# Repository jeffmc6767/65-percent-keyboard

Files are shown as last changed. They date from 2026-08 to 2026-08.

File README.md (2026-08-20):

67% Keyboard
-
A 60-70% keyboard with a customizable oled and 2 rotary encoders. 
Screenshot 2026-08-13 at 2 15 45 PM

Quick start
-

How can you build it yourself. 

1. Buy all the parts in the BOM (Also make sure to buy Cherry MX switches that are 3 or 5 pin) and order a PCB
2. solder everything according to the layout on the PCB
3. Install firmware by plugging in the raspberry pi pico 2wh and flashing it.
4. Customize keys in the software
5. Done!

Features:
-

1. 73 key keyboard, with 2 customizable keys
2. 2 rotary encoders for volume and brightness control(default)
3. Rotary encoders include push button
4. 1 0.91" customizable OLED screen

How it works:
-

The 73 switches and 2 rotary encoders are wired in a matrix, each with a diode to detect which key is pressed. Each switch is soldered directly to the PCB. 

The keyboard will be wireless via bluetooth, 2.4gz, and also supports USBC connection, since the raspberry pi pico2wh has wifi and bluetooth connectivity. 

Here's some images:
-

Screenshot 2026-08-13 at 2 16 21 PM
Screenshot 2026-08-13 at 2 16 12 PM
Screenshot 2026-08-13 at 1 37 29 PM

I will be using PLA matte white to print the case out (because it has no LED's) or petg white depending on what filament I have. 

ROUGH BOM: look at the BOM.csv. 

- 73x switches: $29.99(I own these already)
- 75x 1N4148 Diodes: $5
- 2x PEC11R-4220f-S0024-ND: $8.60
- 1x Raspberry Pi Pico 2WH: $21
- 1x 0.91" OLED: $9
- 1x Tin Lead Sn60-Pb40 (0.6mm, 50g): $12
- 1x PCB: $76
- 6.25U and 2.00U stabilizer: $15

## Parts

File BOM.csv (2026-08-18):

Item | Description | Part Number / Spec | Qty | Unit Price (CAD $) | Subtotal (CAD $) | 13% Tax (CAD $) | Total (CAD $) | Total (USD $) | Link
2 | Switching Diodes | 1N4148 | 75 | 0.07 | 5.00 | 0.65 | 5.65 | 4.07 | https://www.digikey.ca/en/products/detail/onsemi/1N4148/458603
3 | Rotary Encoder | PEC11R-4220F-S0024 | 2 | 4.30 | 8.60 | 1.12 | 9.72 | 7.00 | https://www.digikey.ca/en/products/detail/bourns-inc/PEC11R-4220F-S0024/4499660
4 | Microcontroller Board | Raspberry Pi Pico 2WH | 1 | 11.91 | 11.91 | 1.55 | 13.46 | 9.69 | https://www.digikey.ca/en/products/detail/raspberry-pi/SC1634/26241087
5 | OLED Display Module | 0.91" OLED (I2C) | 1 | 9.00 | 9.00 | 1.17 | 10.17 | 7.32 | https://www.amazon.ca/gp/product/B0CYXW1WPF/ref=ox_sc_saved_image_2?smid=A3NZ63JNHV007B&psc=1
6 | DigiKey Shipping Fee | Flat Shipping Rate | 1 | 15.00 | 15.00 | 0.00 | 15.00 | 10.80
7 | Printed Circuit Board | Custom Keyboard PCB | 1 | 76.00 | 76.00 | 0.00 | 76.00 | 54.72
8 | Keycap Stabilizers | 6.25U and 2.00U Stabilizer Set | 1 | 15.00 | 15.00 | 1.95 | 16.95 | 12.20 | https://www.amazon.ca/gp/product/B0C61X6DNX/ref=ox_sc_saved_title_8?smid=A3FAG29GGXU06M&psc=1
 | Total |  |  |  | 140.51 | 6.44 | 146.95 | 105.80

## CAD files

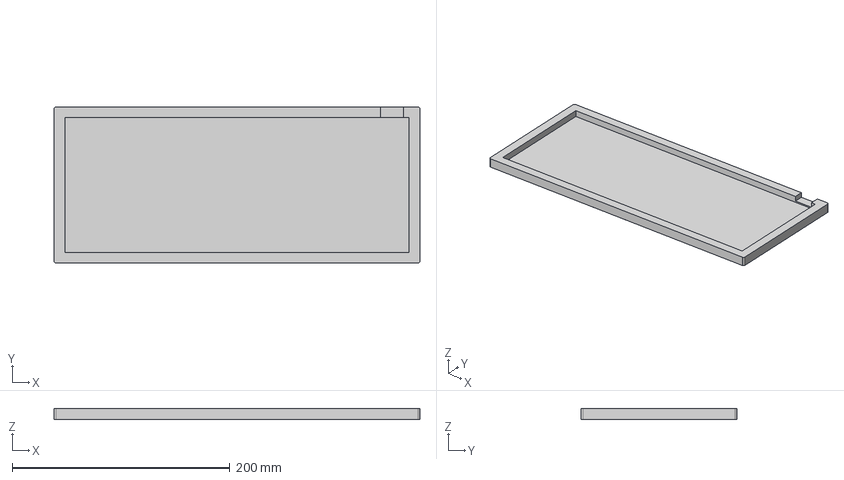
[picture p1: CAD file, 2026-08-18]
CAD/Bottom of case.step
336.4 x 143.7 x 10.0 mm

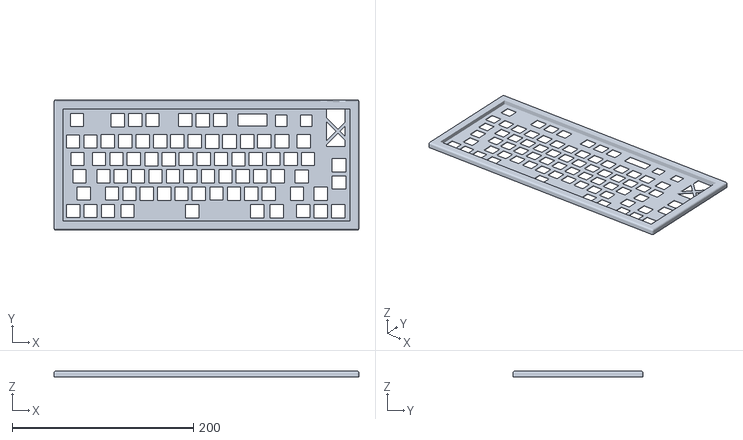
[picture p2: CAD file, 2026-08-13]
Production Files/Keyboard case/Top.stl
336.4 x 143.7 x 6.50

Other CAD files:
CAD/Top of case.step
Production Files/Keyboard case/Bottom.stl

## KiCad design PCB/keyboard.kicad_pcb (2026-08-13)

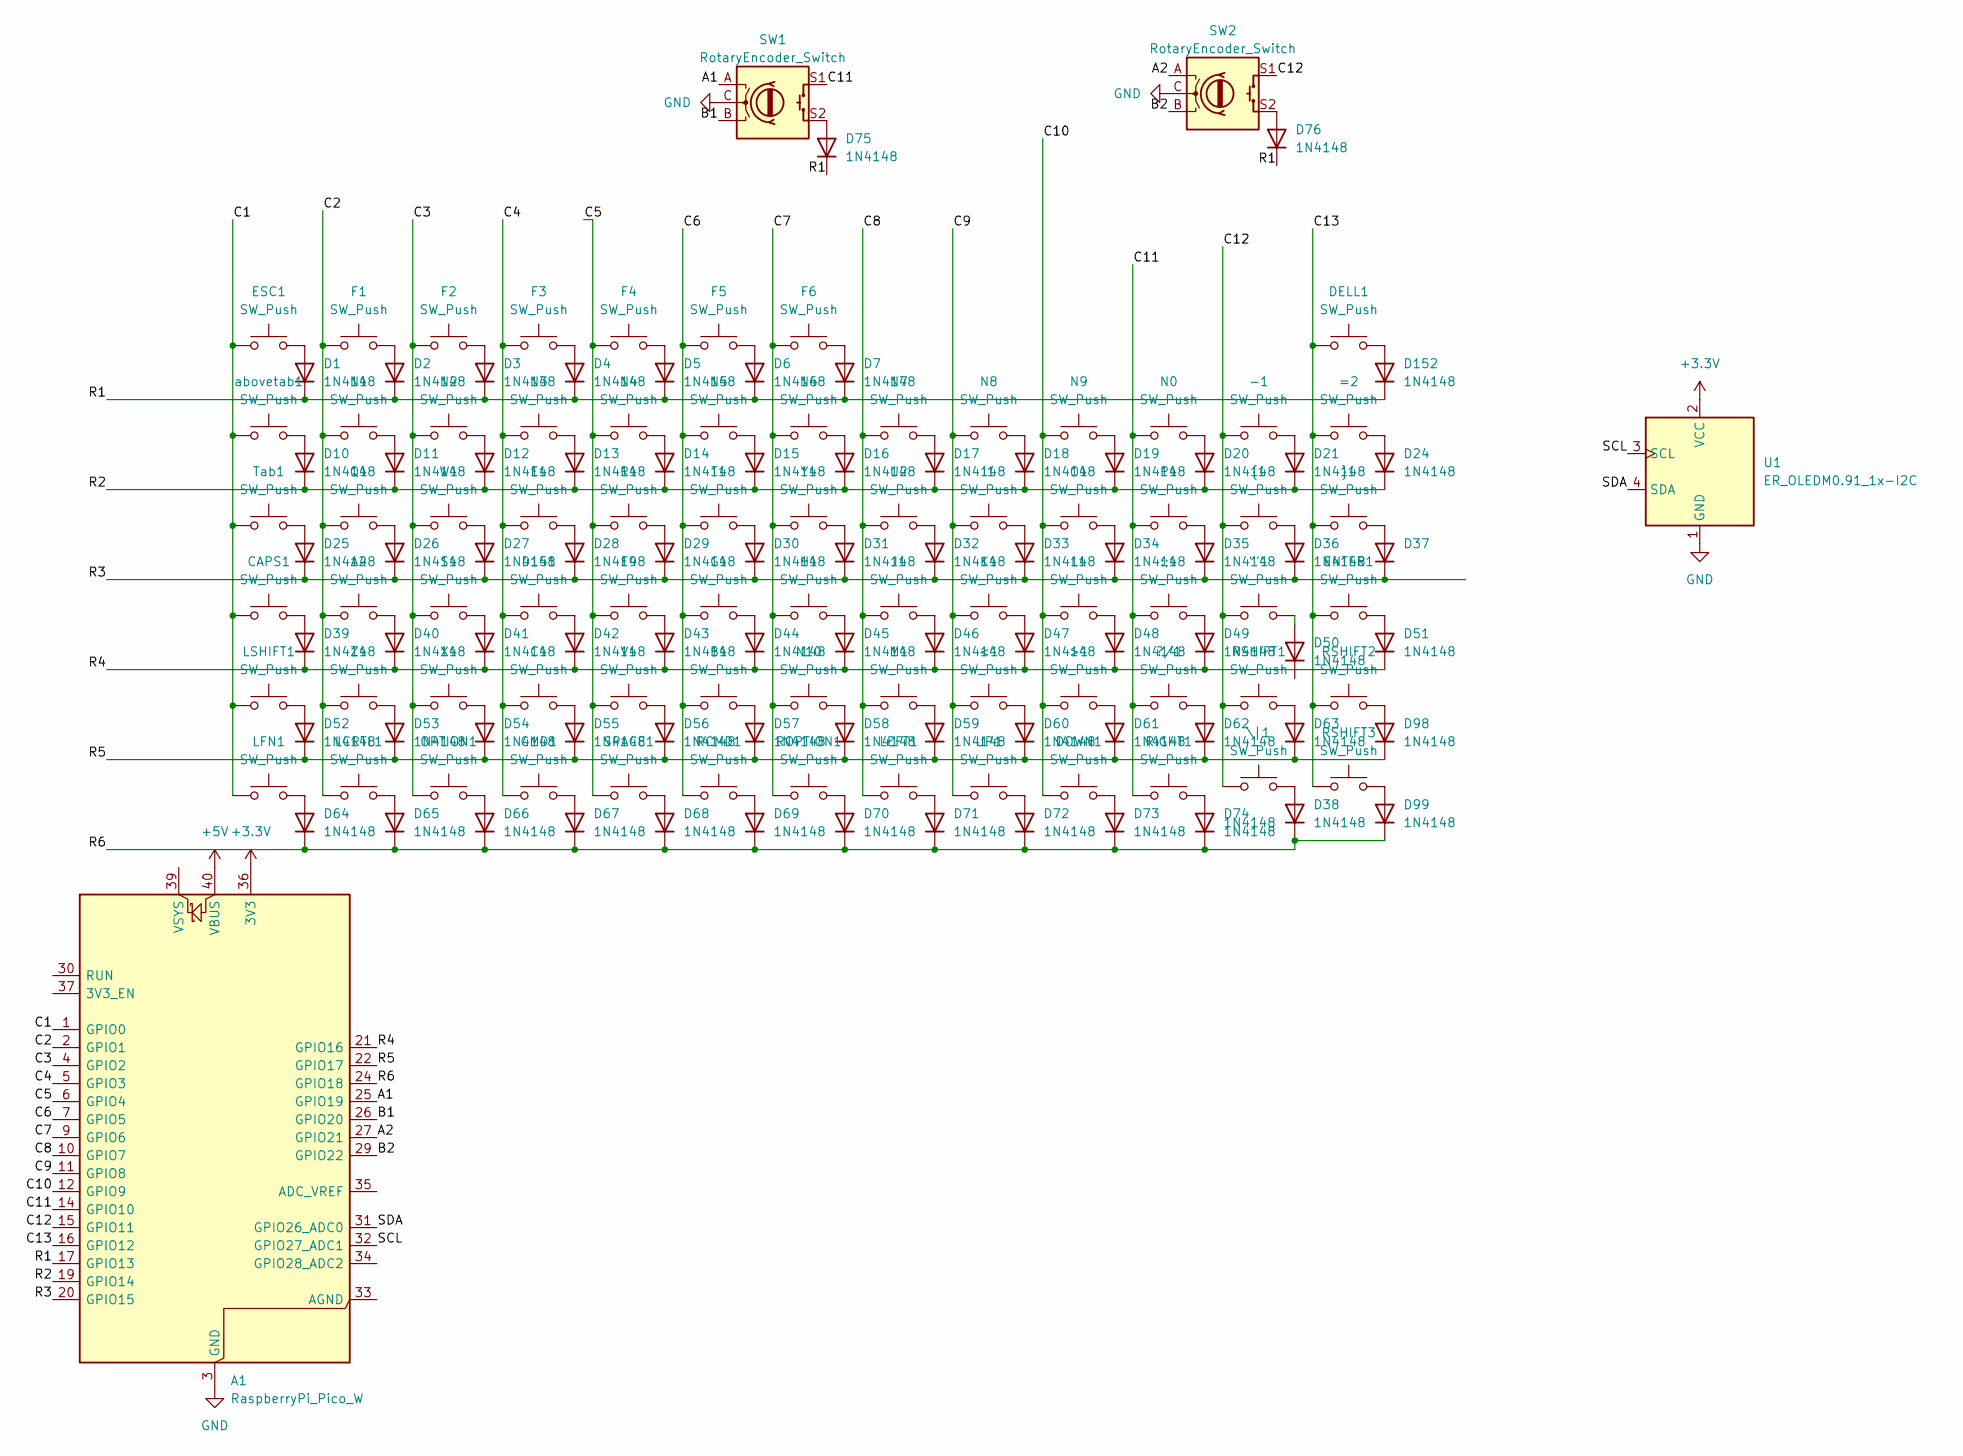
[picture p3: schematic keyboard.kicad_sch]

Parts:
"'1: SW_Push; SW_Cherry_MX_1.00u_PCB-Gateron-KS-3x switch
-1: SW_Push; SW_Cherry_MX_1.00u_PCB-Gateron-KS-3x switch
:;1: SW_Push; SW_Cherry_MX_1.00u_PCB-Gateron-KS-3x switch
<1: SW_Push; SW_Cherry_MX_1.00u_PCB-Gateron-KS-3x switch
=2: SW_Push; SW_Cherry_MX_1.00u_PCB-Gateron-KS-3x switch
>1: SW_Push; SW_Cherry_MX_1.00u_PCB-Gateron-KS-3x switch
?/1: SW_Push; SW_Cherry_MX_1.00u_PCB-Gateron-KS-3x switch
A1: RaspberryPi_Pico_W; RaspberryPi_Pico_W_SMD_HandSolder
A2: SW_Push; SW_Cherry_MX_1.00u_PCB-Gateron-KS-3x switch
B1: SW_Push; SW_Cherry_MX_1.00u_PCB-Gateron-KS-3x switch
C1: SW_Push; SW_Cherry_MX_1.00u_PCB-Gateron-KS-3x switch
CAPS1: SW_Push; SW_Cherry_MX_1.75u_PCB-Gateron-KS-3X
CMD1: SW_Push; SW_Cherry_MX_1.25u_PCB-Gateron-KS-3X
D1, D2, D3, D4, D5, D6, D7, D10, D11, D12, D13, D14, D15, D16, D17, D18, D19, D20, D21, D24, D25, D26, D27, D28, D29, D30, D31, D32, D33, D34, D35, D36, D37, D38, D39, D40, D41, D42, D43, D44, D45, D46, D47, D48, D49, D50, D51, D52, D53, D54, D55, D56, D57, D58, D59, D60, D61, D62, D63, D64, D65, D66, D67, D68, D69, D70, D71, D72, D73, D74, D75, D76, D98, D99, D152: 1N4148; D_DO-35_SOD27_P7.62mm_Horizontal
D151: SW_Push; SW_Cherry_MX_1.00u_PCB-Gateron-KS-3x switch
DELL1: SW_Push; SW_Cherry_MX_1.50u_PCB-Gateron-KS-3X
DOWN1: SW_Push; SW_Cherry_MX_1.00u_PCB-Gateron-KS-3x switch
E1: SW_Push; SW_Cherry_MX_1.00u_PCB-Gateron-KS-3x switch
ENTER1: SW_Push; SW_Cherry_MX_1.75u_PCB-Gateron-KS-3X
ESC1: SW_Push; SW_Cherry_MX_1.50u_PCB-Gateron-KS-3X
F1, F2, F3, F4, F5, F6, F9: SW_Push; SW_Cherry_MX_1.00u_PCB-Gateron-KS-3x switch
G1: SW_Push; SW_Cherry_MX_1.00u_PCB-Gateron-KS-3x switch
H1: SW_Push; SW_Cherry_MX_1.00u_PCB-Gateron-KS-3x switch
I1: SW_Push; SW_Cherry_MX_1.00u_PCB-Gateron-KS-3x switch
J1: SW_Push; SW_Cherry_MX_1.00u_PCB-Gateron-KS-3x switch
K1: SW_Push; SW_Cherry_MX_1.00u_PCB-Gateron-KS-3x switch
L1: SW_Push; SW_Cherry_MX_1.00u_PCB-Gateron-KS-3x switch
LCRTL1: SW_Push; SW_Cherry_MX_1.00u_PCB-Gateron-KS-3x switch
LEFT1: SW_Push; SW_Cherry_MX_1.00u_PCB-Gateron-KS-3x switch
LFN1: SW_Push; SW_Cherry_MX_1.00u_PCB-Gateron-KS-3x switch
LSHIFT1: SW_Push; SW_Cherry_MX_2.25u_PCB-Gateron-KS-3X
M1: SW_Push; SW_Cherry_MX_1.00u_PCB-Gateron-KS-3x switch
N0, N1, N2, N3, N4, N5, N6, N7, N8, N9, N10: SW_Push; SW_Cherry_MX_1.00u_PCB-Gateron-KS-3x switch
O1: SW_Push; SW_Cherry_MX_1.00u_PCB-Gateron-KS-3x switch
OPTION1: SW_Push; SW_Cherry_MX_1.00u_PCB-Gateron-KS-3x switch
P1: SW_Push; SW_Cherry_MX_1.00u_PCB-Gateron-KS-3x switch
Q1: SW_Push; SW_Cherry_MX_1.00u_PCB-Gateron-KS-3x switch
R1: SW_Push; SW_Cherry_MX_1.00u_PCB-Gateron-KS-3x switch
RCMD1: SW_Push; SW_Cherry_MX_1.25u_PCB-Gateron-KS-3X
RIGHT1: SW_Push; SW_Cherry_MX_1.00u_PCB-Gateron-KS-3x switch
ROPTION1: SW_Push; SW_Cherry_MX_1.00u_PCB-Gateron-KS-3x switch
RSHIFT1: SW_Push; SW_Cherry_MX_1.75u_PCB-Gateron-KS-3X
RSHIFT2, RSHIFT3: SW_Push; SW_Cherry_MX_1.00u_PCB-Gateron-KS-3x switch
S1: SW_Push; SW_Cherry_MX_1.00u_PCB-Gateron-KS-3x switch
SPACE1: SW_Push; SW_Cherry_MX_6.25u_PCB-Gateron-KS-3X-switch
SW1, SW2: RotaryEncoder_Switch; RotaryEncoder_Alps_EC11E-Switch_Vertical_H20mm
T1: SW_Push; SW_Cherry_MX_1.00u_PCB-Gateron-KS-3x switch
Tab1: SW_Push; SW_Cherry_MX_1.50u_PCB-Gateron-KS-3X
U1: ER_OLEDM0.91_1x-I2C
U2: SW_Push; SW_Cherry_MX_1.00u_PCB-Gateron-KS-3x switch
UP1: SW_Push; SW_Cherry_MX_1.00u_PCB-Gateron-KS-3x switch
V1: SW_Push; SW_Cherry_MX_1.00u_PCB-Gateron-KS-3x switch
W1: SW_Push; SW_Cherry_MX_1.00u_PCB-Gateron-KS-3x switch
X1: SW_Push; SW_Cherry_MX_1.00u_PCB-Gateron-KS-3x switch
Y1: SW_Push; SW_Cherry_MX_1.00u_PCB-Gateron-KS-3x switch
Z1: SW_Push; SW_Cherry_MX_1.00u_PCB-Gateron-KS-3x switch
\|1: SW_Push; SW_Cherry_MX_1.00u_PCB-Gateron-KS-3x switch
abovetab1: SW_Push; SW_Cherry_MX_1.00u_PCB-Gateron-KS-3x switch
{1: SW_Push; SW_Cherry_MX_1.00u_PCB-Gateron-KS-3x switch
}1: SW_Push; SW_Cherry_MX_1.00u_PCB-Gateron-KS-3x switch

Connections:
+3.3V: A1.36 (3V3), U1.2 (VCC)
+5V: A1.40 (VBUS)
/A1: A1.25 (GPIO19), SW1.A
/A2: A1.27 (GPIO21), SW2.A
/B1: A1.26 (GPIO20), SW1.B
/B2: A1.29 (GPIO22), SW2.B
/C1: A1.1 (GPIO0), CAPS1.1, ESC1.1, LFN1.1, LSHIFT1.1, Tab1.1, abovetab1.1
/C2: A1.2 (GPIO1), A2.1, F1.1, LCRTL1.1, N1.1, Q1.1, Z1.1
/C3: A1.4 (GPIO2), F2.1, N2.1, OPTION1.1, S1.1, W1.1, X1.1
/C4: A1.5 (GPIO3), C1.1, CMD1.1, D151.1, E1.1, F3.1, N3.1
/C5: A1.6 (GPIO4), F4.1, F9.1, N4.1, R1.1, SPACE1.1, V1.1
/C6: A1.7 (GPIO5), B1.1, F5.1, G1.1, N5.1, RCMD1.1, T1.1
/C7: A1.9 (GPIO6), F6.1, H1.1, N6.1, N10.1, ROPTION1.1, Y1.1
/C8: A1.10 (GPIO7), J1.1, LEFT1.1, M1.1, N7.1, U2.1
/C9: <1.1, A1.11 (GPIO8), I1.1, K1.1, N8.1, UP1.1
/C10: >1.1, A1.12 (GPIO9), DOWN1.1, L1.1, N9.1, O1.1
/C11: :;1.1, ?/1.1, A1.14 (GPIO10), N0.1, P1.1, RIGHT1.1, SW1.S1
/C12: "'1.1, -1.1, A1.15 (GPIO11), RSHIFT1.1, SW2.S1, \|1.1, {1.1
/C13: =2.1, A1.16 (GPIO12), DELL1.1, ENTER1.1, RSHIFT2.1, RSHIFT3.1, }1.1
/R1: A1.17 (GPIO13), D1.1 (K), D2.1 (K), D3.1 (K), D4.1 (K), D5.1 (K), D6.1 (K), D7.1 (K), D75.1 (K), D76.1 (K), D152.1 (K)
/R2: A1.19 (GPIO14), D10.1 (K), D11.1 (K), D12.1 (K), D13.1 (K), D14.1 (K), D15.1 (K), D16.1 (K), D17.1 (K), D18.1 (K), D19.1 (K), D20.1 (K), D21.1 (K), D24.1 (K)
/R3: A1.20 (GPIO15), D25.1 (K), D26.1 (K), D27.1 (K), D28.1 (K), D29.1 (K), D30.1 (K), D31.1 (K), D32.1 (K), D33.1 (K), D34.1 (K), D35.1 (K), D36.1 (K), D37.1 (K)
/R4: A1.21 (GPIO16), D39.1 (K), D40.1 (K), D41.1 (K), D42.1 (K), D43.1 (K), D44.1 (K), D45.1 (K), D46.1 (K), D47.1 (K), D48.1 (K), D49.1 (K), D51.1 (K)
/R5: A1.22 (GPIO17), D52.1 (K), D53.1 (K), D54.1 (K), D55.1 (K), D56.1 (K), D57.1 (K), D58.1 (K), D59.1 (K), D60.1 (K), D61.1 (K), D62.1 (K), D63.1 (K), D98.1 (K)
/R6: A1.24 (GPIO18), D38.1 (K), D64.1 (K), D65.1 (K), D66.1 (K), D67.1 (K), D68.1 (K), D69.1 (K), D70.1 (K), D71.1 (K), D72.1 (K), D73.1 (K), D74.1 (K), D99.1 (K)
/SCL: A1.32 (GPIO27_ADC1), U1.3 (SCL)
/SDA: A1.31 (GPIO26_ADC0), U1.4 (SDA)
GND: A1.3 (GND), A1.8 (GND), A1.13 (GND), A1.18 (GND), A1.23 (GND), A1.28 (GND), A1.38 (GND), SW1.C, SW2.C, U1.1 (GND)
unnamed: D1.2 (A), ESC1.2
unnamed: D2.2 (A), F1.2
unnamed: D3.2 (A), F2.2
unnamed: D4.2 (A), F3.2
unnamed: D5.2 (A), F4.2
unnamed: D6.2 (A), F5.2
unnamed: D7.2 (A), F6.2
unnamed: D10.2 (A), abovetab1.2
unnamed: D11.2 (A), N1.2
unnamed: D12.2 (A), N2.2
unnamed: D13.2 (A), N3.2
unnamed: D14.2 (A), N4.2
unnamed: D15.2 (A), N5.2
unnamed: D16.2 (A), N6.2
unnamed: D17.2 (A), N7.2
unnamed: D18.2 (A), N8.2
unnamed: D19.2 (A), N9.2
unnamed: D20.2 (A), N0.2
unnamed: -1.2, D21.2 (A)
unnamed: =2.2, D24.2 (A)
unnamed: D25.2 (A), Tab1.2
unnamed: D26.2 (A), Q1.2
unnamed: D27.2 (A), W1.2
unnamed: D28.2 (A), E1.2
unnamed: D29.2 (A), R1.2
unnamed: D30.2 (A), T1.2
unnamed: D31.2 (A), Y1.2
unnamed: D32.2 (A), U2.2
unnamed: D33.2 (A), I1.2
unnamed: D34.2 (A), O1.2
unnamed: D35.2 (A), P1.2
unnamed: D36.2 (A), {1.2
unnamed: D37.2 (A), }1.2
unnamed: D38.2 (A), \|1.2
unnamed: CAPS1.2, D39.2 (A)
unnamed: A2.2, D40.2 (A)
unnamed: D41.2 (A), S1.2
unnamed: D42.2 (A), D151.2
unnamed: D43.2 (A), F9.2
unnamed: D44.2 (A), G1.2
unnamed: D45.2 (A), H1.2
unnamed: D46.2 (A), J1.2
unnamed: D47.2 (A), K1.2
unnamed: D48.2 (A), L1.2
unnamed: :;1.2, D49.2 (A)
unnamed: "'1.2, D50.2 (A_2)
unnamed: D51.2 (A), ENTER1.2
unnamed: D52.2 (A), LSHIFT1.2
unnamed: D53.2 (A), Z1.2
unnamed: D54.2 (A), X1.2
unnamed: C1.2, D55.2 (A)
unnamed: D56.2 (A), V1.2
unnamed: B1.2, D57.2 (A)
unnamed: D58.2 (A), N10.2
unnamed: D59.2 (A), M1.2
unnamed: <1.2, D60.2 (A)
unnamed: >1.2, D61.2 (A)
unnamed: ?/1.2, D62.2 (A)
unnamed: D63.2 (A), RSHIFT1.2
unnamed: D64.2 (A), LFN1.2
unnamed: D65.2 (A), LCRTL1.2
unnamed: D66.2 (A), OPTION1.2
unnamed: CMD1.2, D67.2 (A)
unnamed: D68.2 (A), SPACE1.2
unnamed: D69.2 (A), RCMD1.2
unnamed: D70.2 (A), ROPTION1.2
unnamed: D71.2 (A), LEFT1.2
unnamed: D72.2 (A), UP1.2
unnamed: D73.2 (A), DOWN1.2
unnamed: D74.2 (A), RIGHT1.2
unnamed: D75.2 (A), SW1.S2
unnamed: D76.2 (A), SW2.S2
unnamed: D98.2 (A), RSHIFT2.2
unnamed: D99.2 (A), RSHIFT3.2
unnamed: D152.2 (A), DELL1.2

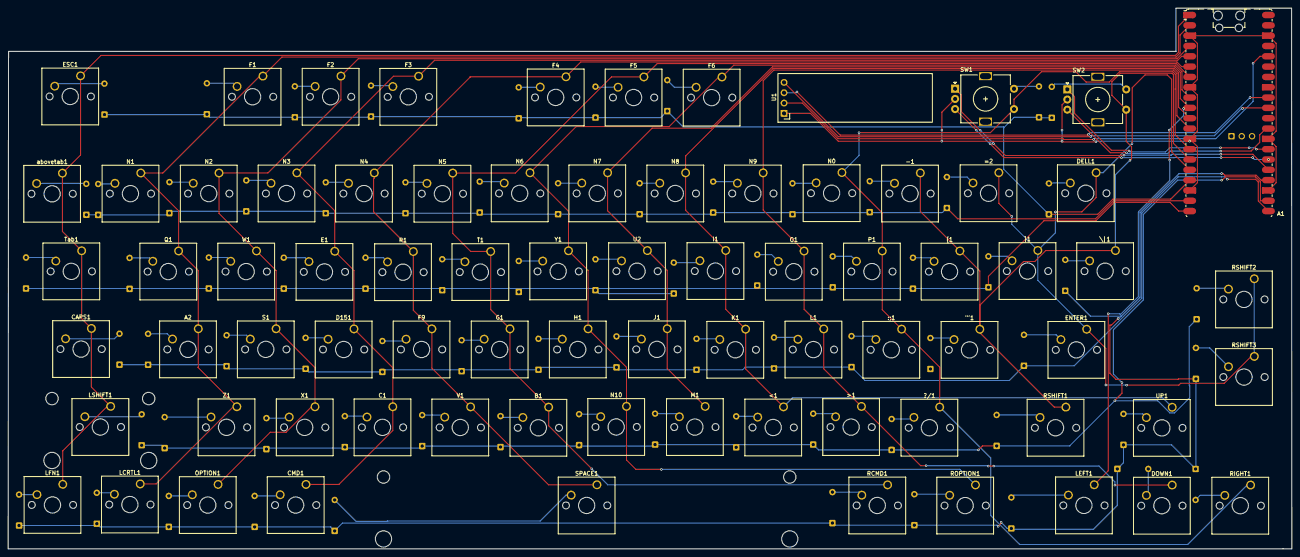
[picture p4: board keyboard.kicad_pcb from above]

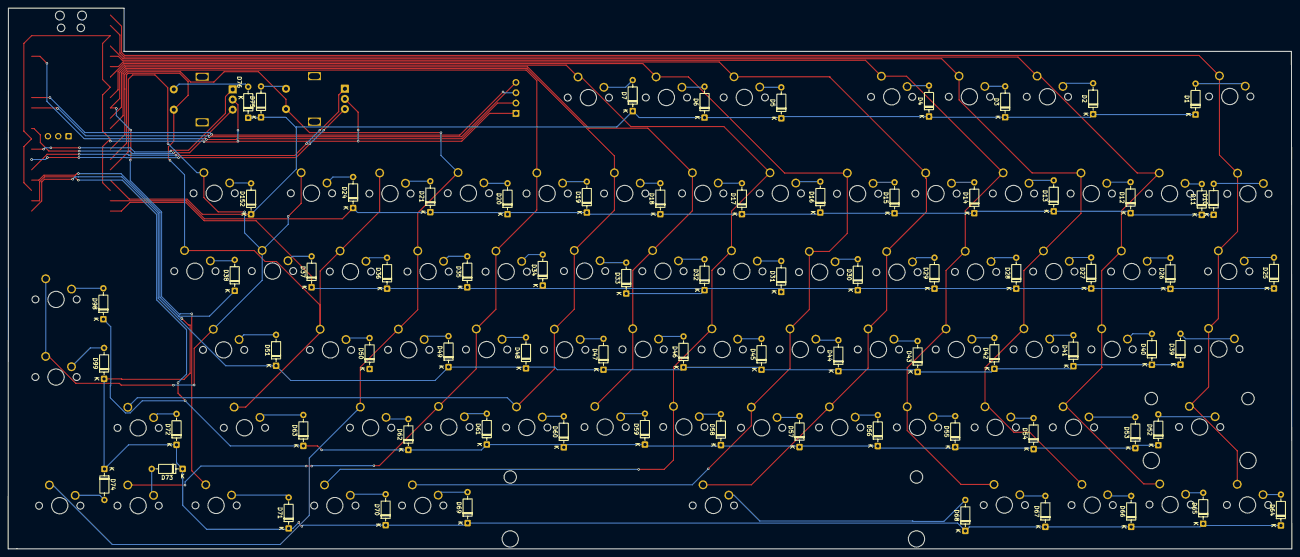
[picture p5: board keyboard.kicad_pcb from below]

Board: 2 copper layers, 315.9 x 133.1 mm, 152 parts (75 on the bottom side), 102 nets.

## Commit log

2026-08-13 Fix .history tracking and add .gitignore
    [BOM.csv, Bottom.stl, KS-3X Full Black Switch KS-3A10B060NN-X.stp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]
2026-08-13 ad BOM
    [BOM.csv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]
2026-08-13 Save local work
    [keyboard.kicad_pcb]
2026-08-13 Add BOM notice to README
2026-08-20 Add DIY build instructions to README
    Added instructions for building the wireless keyboard.
2026-08-20 updated folder names
    [Bottom of case.step, Top of case.step, keyboard.kicad_pcb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]
